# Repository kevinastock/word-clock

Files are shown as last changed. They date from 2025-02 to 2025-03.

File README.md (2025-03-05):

# Word Clock

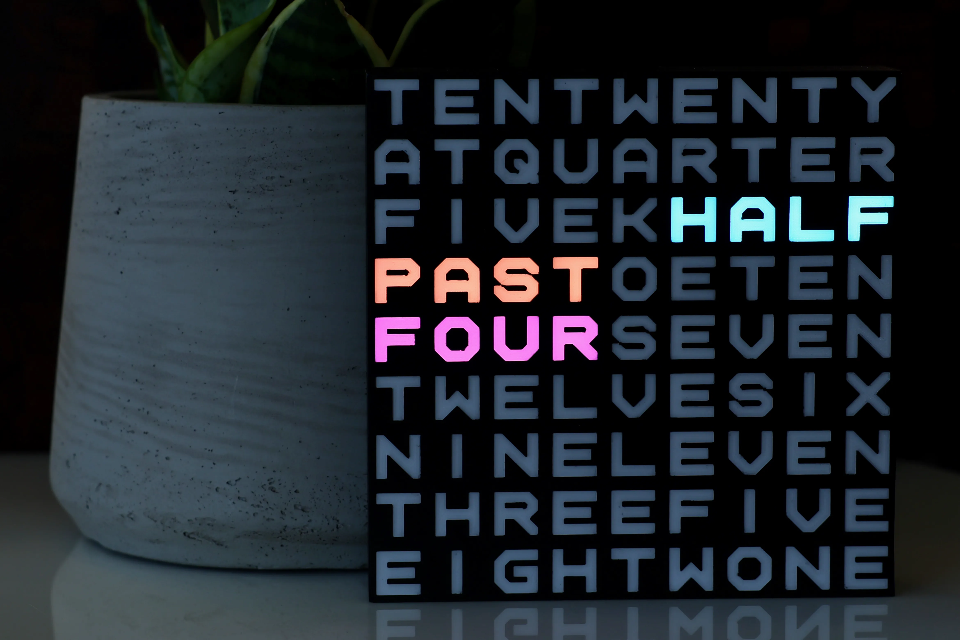
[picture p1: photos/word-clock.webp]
the clock


This project is a 3D-printed, word clock that displays the time using a 9×9 letter grid. 
The entire front enclosure was designed as a single piece that works as the display, LED adapter, light baffle, and diffuser. 
A TinyPICO microcontroller drives a matrix of APA102C LEDs and sets the time via NTP and [WorldTimeAPI](http://worldtimeapi.org).
Configuration is handled via an onboard accelerometer to adjust brightness, manually shift time zone, or reset WiFi credentials.
The backplate is secured with M2 heat-set inserts and hex socket screws, provides cable strain relief, and mounts for the electronics.

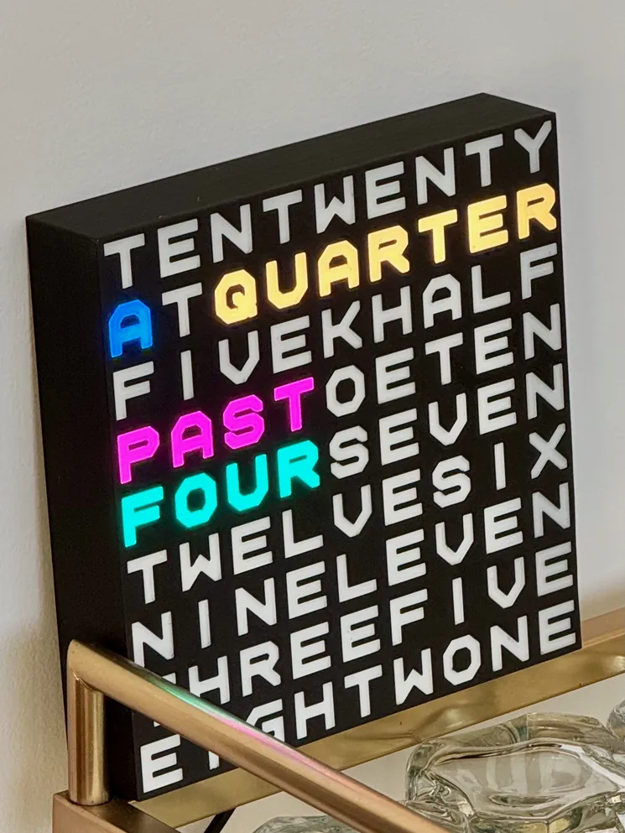
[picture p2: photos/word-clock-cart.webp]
the clock


## Bill of Materials

### Electronics
- **Microcontroller**: [TinyPICO](https://www.tinypico.com/)
- **Accelerometer**: [Adafruit LIS3DH](https://www.adafruit.com/product/2809)
- **Level Shifter**: [74AHCT125](https://www.adafruit.com/product/1787)
- **LEDs**: 16x16 APA102C LED matrix on a flexible pcb.
- **Protoboard**: [Amazon Link](https://www.amazon.com/gp/product/B071R3BFNL)
- **Wires / Connectors**: Assorted jumpers or soldered connections. Wago connectors were used in early prototypes but are optional.

### Mechanical
- **3D-Printed Front Enclosure**: Generated by `.scad` files in this repository and then exported to STL.
- **3D-Printed Backplate**: Also generated by `.scad` files, with holes sized for M2 heat-set inserts.
- **Heat Set Inserts**: [M2x8x2.5 Brass Knurled Inserts](https://www.amazon.com/Hilitchi-Knurled-Threaded-Function-Projects/dp/B07VFZWWXY)
- **Screws**: [M2x8 Hex Socket Head Screws](https://www.amazon.com/DYWISHKEY-Pieces-Socket-Screws-Wrench/dp/B07W5J19Y5)

### Tools & Supplies
- 3D Printer (capable of two-color printing or manual filament swaps). I used a Ultimaker UM3.
- Krylon Matte Finish (1311) or similar clear matte spray for surface finishing
- Soldering iron, solder, and basic electronics tools
- Heat gun or soldering iron for heat-set inserts

## 3D Printing

1. **Generate SCAD Files**: `python3 clock.py` will produce OpenSCAD files for both the front and backplate.
2. **Export to STL**:  Open each .scad file in OpenSCAD and render/export to .stl.
3. **Slicing**: The print uses three colors. If using a dual-extruder printer, insert a pause command in your slicer after the first few layers to swap from clear to white manually.
  If using a printer that can print three colors at once, the python code can be modified to produce three separate color pieces for the front.
4. **Post-Processing**: After printing, apply a coat of Krylon Matte Finish (1311) to the clock face. This helps diffuse light more evenly and improves the overall look.

## Firmware & Code

This project was built and uploaded using the Arduino IDE. Make sure you have the necessary ESP32 board definitions installed.

### Board Manager

You'll need to install `esp32` version `2.0.17`. The `3.x` versions will not work with this code.

### Required Libraries

| Library | Version | 
| --- | --- |
| Adafruit BusIO | 1.16.1 |
| Adafruit LIS3DH | 1.3.0 |
| Adafruit Unified Sensor | 1.1.14 |
| ArduinoJson | 7.0.4 |
| AsyncTCP (by dvarrel) | 1.1.4 |
| ESPAsyncTCP (by dvarrel) | 1.2.4 |
| ESPAsyncWebServer | 3.1.0 |
| FastLED | 3.7.8 |
| TinyPICO Helper Library | 1.5.0 |

## Electronics & Wiring

I don't have a real guide to wiring, here's a photo of one of the clocks internals:

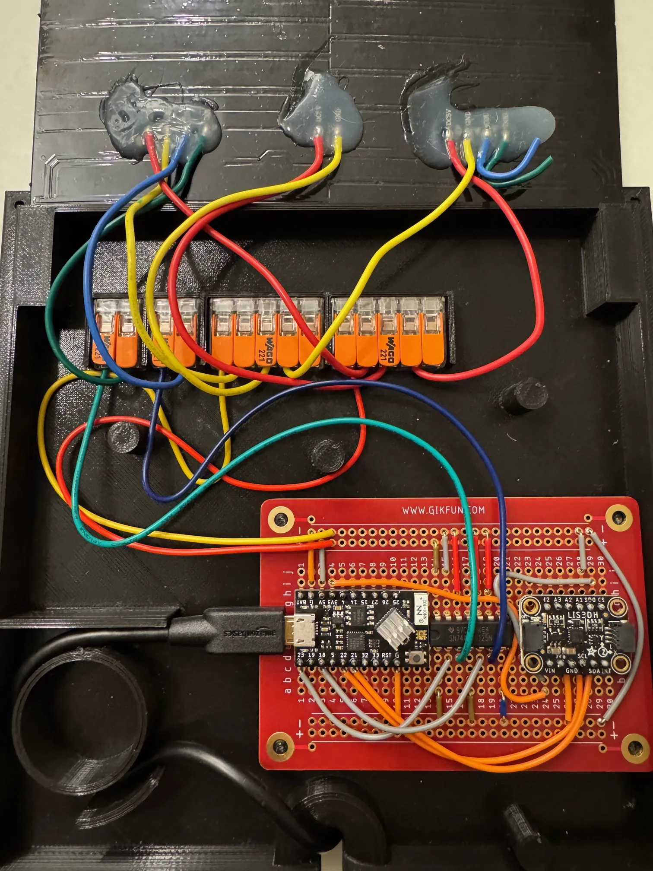
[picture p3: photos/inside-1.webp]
wiring

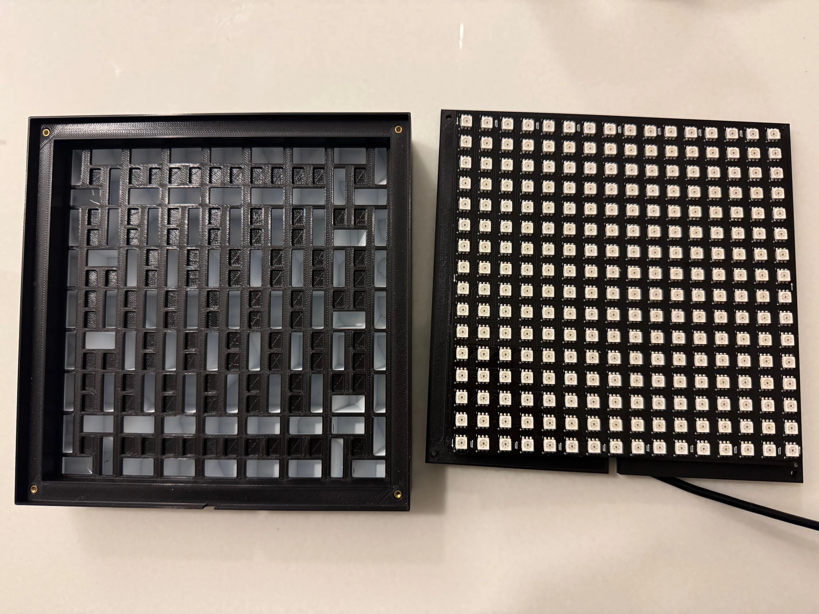
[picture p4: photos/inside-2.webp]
assembly


## License & Acknowledgments

Except as noted here, this project is released under the AGPL-3.0 license.

**Exceptions**:
 - Name Smile Font [Copyright © by Chequered Ink](https://chequered.ink) [FontSpace](https://www.fontspace.com/name-smile-font-f30803)
 - The forked code from [ESPConnect](https://github.com/ayushsharma82/ESPConnect) is under its GPL license.
 - The forked code from [NTPClient](https://github.com/arduino-libraries/NTPClient) is under its MIT license

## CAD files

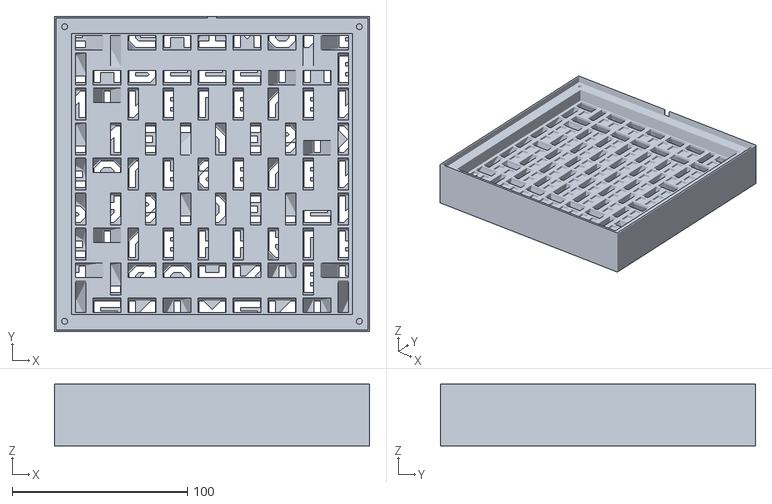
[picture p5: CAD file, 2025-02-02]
generated/clock-black.stl
180.0 x 180.0 x 35.3

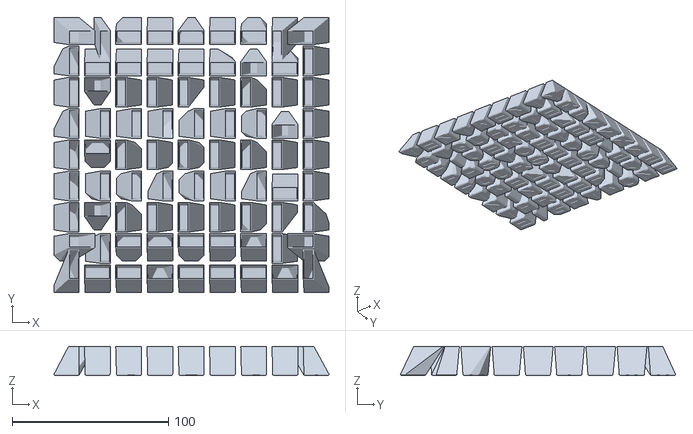
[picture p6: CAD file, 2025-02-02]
generated/clock-white.stl
176.0 x 176.0 x 18.7

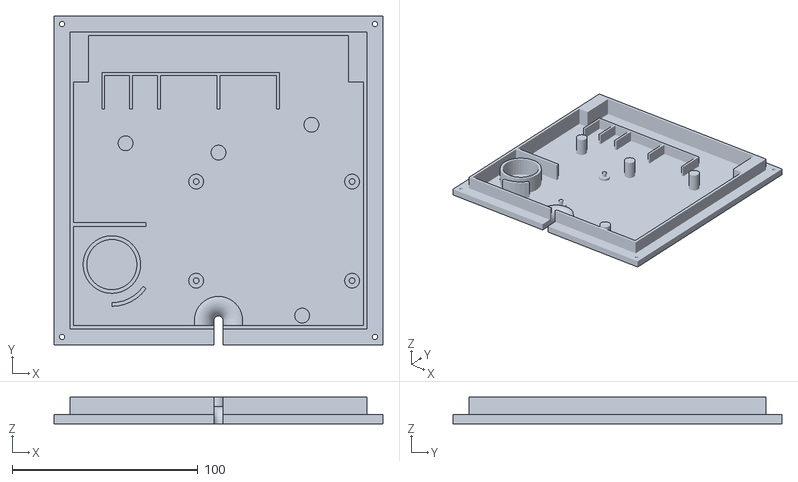
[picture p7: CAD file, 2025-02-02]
generated/clock-back.stl
177.0 x 177.0 x 14.5

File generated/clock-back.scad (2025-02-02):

module m5() {
    cube([177, 177, 5], center=false);
}

module m4() {
    translate([1.5, 1.5, 0])
        m5();
}

module m7() {
    cube([159.75, 159.75, 14.5], center=false);
}

module m6() {
    translate([10.125, 10.125, 0])
        m7();
}

module m3() {
    union() {
        m4();
        m6();
    }
}

module m10() {
    cylinder(h=1000000, d=2.85, center=false, $fn=20);
}

module m11() {
    cylinder(h=2, d=4.5, center=false, $fn=20);
}

module m9() {
    union() {
        m10();
        m11();
    }
}

module m8() {
    translate([5.832738110421965, 5.832738110421965, 0])
        m9();
}

module m14() {
    cylinder(h=1000000, d=2.85, center=false, $fn=20);
}

module m15() {
    cylinder(h=2, d=4.5, center=false, $fn=20);
}

module m13() {
    union() {
        m14();
        m15();
    }
}

module m12() {
    translate([5.832738110421965, 174.16726188957804, 0])
        m13();
}

module m18() {
    cylinder(h=1000000, d=2.85, center=false, $fn=20);
}

module m19() {
    cylinder(h=2, d=4.5, center=false, $fn=20);
}

module m17() {
    union() {
        m18();
        m19();
    }
}

module m16() {
    translate([174.16726188957804, 5.832738110421965, 0])
        m17();
}

module m22() {
    cylinder(h=1000000, d=2.85, center=false, $fn=20);
}

module m23() {
    cylinder(h=2, d=4.5, center=false, $fn=20);
}

module m21() {
    union() {
        m22();
        m23();
    }
}

module m20() {
    translate([174.16726188957804, 174.16726188957804, 0])
        m21();
}

module m25() {
    cube([155.75, 155.75, 1000000], center=false);
}

module m24() {
    translate([12.125, 12.125, 1.5])
        m25();
}

module m27() {
    cube([5, 29.25, 1000000], center=true);
}

module m26() {
    translate([90.0, 0, 0])
        m27();
}

module m29() {
    cylinder(h=1000000, d=5, center=true, $fn=40);
}

module m28() {
    translate([90.0, 14.625, 0])
        m29();
}

module m2() {
    difference() {
        m3();
        m8();
        m12();
        m16();
        m20();
        m24();
        m26();
        m28();
    }
}

module m33() {
    cylinder(h=3.5, d=8, center=true, $fn=40);
}

module m32() {
    translate([0, 0, 1.75])
        m33();
}

module m35() {
    cylinder(h=6.5, d=3.1, center=true, $fn=40);
}

module m34() {
    translate([0, 0, 3.25])
        m35();
}

module m31() {
    union() {
        m32();
        m34();
    }
}

module m30() {
    translate([161.875, 36.125, 0])
        m31();
}

module m39() {
    cylinder(h=3.5, d=8, center=true, $fn=40);
}

module m38() {
    translate([0, 0, 1.75])
        m39();
}

module m41() {
    cylinder(h=6.5, d=3.1, center=true, $fn=40);
}

module m40() {
    translate([0, 0, 3.25])
        m41();
}

module m37() {
    union() {
        m38();
        m40();
    }
}

module m36() {
    translate([77.975, 36.125, 0])
        m37();
}

module m45() {
    cylinder(h=3.5, d=8, center=true, $fn=40);
}

module m44() {
    translate([0, 0, 1.75])
        m45();
}

module m47() {
    cylinder(h=6.5, d=3.1, center=true, $fn=40);
}

module m46() {
    translate([0, 0, 3.25])
        m47();
}

module m43() {
    union() {
        m44();
        m46();
    }
}

module m42() {
    translate([161.875, 89.425, 0])
        m43();
}

module m51() {
    cylinder(h=3.5, d=8, center=true, $fn=40);
}

module m50() {
    translate([0, 0, 1.75])
        m51();
}

module m53() {
    cylinder(h=6.5, d=3.1, center=true, $fn=40);
}

module m52() {
    translate([0, 0, 3.25])
        m53();
}

module m49() {
    union() {
        m50();
        m52();
    }
}

module m48() {
    translate([77.975, 89.425, 0])
        m49();
}

module m55() {
    cylinder(h=14.5, d=8, center=false, $fn=40);
}

module m54() {
    translate([140, 120, 0])
        m55();
}

module m57() {
    cylinder(h=14.5, d=8, center=false, $fn=40);
}

module m56() {
    translate([40, 110, 0])
        m57();
}

module m59() {
    cylinder(h=14.5, d=8, center=false, $fn=40);
}

module m58() {
    translate([90.0, 105, 0])
        m59();
}

module m61() {
    cylinder(h=14.5, d=8, center=false, $fn=40);
}

module m60() {
    translate([135.0, 17.325, 0])
        m61();
}

module m63() {
    cube([8.0001, 25.0001, 14.5], center=false);
}

module m62() {
    translate([12.125, 142.875, 0])
        m63();
}

module m65() {
    cube([8.0001, 25.0001, 14.5], center=false);
}

module m64() {
    translate([159.875, 142.875, 0])
        m65();
}

module m67() {
    cube([38.849999999999994, 2, 14.5], center=false);
}

module m66() {
    translate([12.125, 65.275, 0])
        m67();
}

module m70() {
    cylinder(h=14.5, d=31, center=false, $fn=40);
}

module m71() {
    cylinder(h=1000000, d=27, center=false, $fn=40);
}

module m69() {
    difference() {
        m70();
        m71();
    }
}

module m68() {
    translate([32.625, 44.775, 0])
        m69();
}

module m74() {
    cylinder(h=14.5, d=45, center=false, $fn=40);
}

module m75() {
    cylinder(h=1000000, d=41, center=false, $fn=40);
}

module m77() {
    cube([1000000, 1000000, 1000000], center=true);
}

module m76() {
    translate([-500000.0, 0, 0])
        m77();
}

module m80() {
    cube([1000000, 1000000, 1000000], center=true);
}

module m79() {
    translate([0, 500000.0, 0])
        m80();
}

module m78() {
    rotate([0, 0, -35])
        m79();
}

module m73() {
    difference() {
        m74();
        m75();
        m76();
        m78();
    }
}

module m72() {
    translate([32.625, 44.775, 0])
        m73();
}

module m83() {
    cube([95.5, 19.5, 9.5], center=false);
}

module m85() {
    cube([13.5, 18, 1000000], center=false);
}

module m84() {
    translate([1.5, 0, 0])
        m85();
}

module m87() {
    cube([13.5, 18, 1000000], center=false);
}

module m86() {
    translate([16.5, 0, 0])
        m87();
}

module m89() {
    cube([30.5, 18, 1000000], center=false);
}

module m88() {
    translate([31.5, 0, 0])
        m89();
}

module m91() {
    cube([30.5, 18, 1000000], center=false);
}

module m90() {
    translate([63.5, 0, 0])
        m91();
}

module m82() {
    difference() {
        m83();
        m84();
        m86();
        m88();
        m90();
    }
}

module m81() {
    translate([27.25, 128.5, 0])
        m82();
}

module m100() {
    circle(r=8, $fn=40);
}

module m99() {
    translate([10.5, 0, 0])
        m100();
}

module m98() {
    rotate_extrude(convexity=10, $fn=40)
        m99();
}

module m102() {
    cube([1000000, 1000000, 1000000], center=true);
}

module m101() {
    translate([0, 0, -500000.0])
        m102();
}

module m104() {
    cube([1000000, 1000000, 1000000], center=true);
}

module m103() {
    translate([0, -500000.0, 0])
        m104();
}

module m97() {
    difference() {
        m98();
        m101();
        m103();
    }
}

module m105() {
    cylinder(h=1000000, d=26, center=true, $fn=40);
}

module m96() {
    intersection() {
        m97();
        m105();
    }
}

module m95() {
    translate([0, 2.5, 0])
        m96();
}

module m108() {
    cylinder(h=2.5, center=false, r=8, $fn=40);
}

module m107() {
    rotate([-90, 0, 0])
        m108();
}

module m106() {
    translate([10.5, 0, 0])
        m107();
}

module m111() {
    cylinder(h=2.5, center=false, r=8, $fn=40);
}

module m110() {
    rotate([-90, 0, 0])
        m111();
}

module m109() {
    translate([-10.5, 0, 0])
        m110();
}

module m94() {
    union() {
        m95();
        m106();
        m109();
    }
}

module m113() {
    cube([1000000, 1000000, 1000000], center=true);
}

module m112() {
    translate([0, 0, -500000.0])
        m113();
}

module m115() {
    cube([1000000, 1000000, 1000000], center=true);
}

module m114() {
    translate([500013.0, 0, 0])
        m115();
}

module m117() {
    cube([1000000, 1000000, 1000000], center=true);
}

module m116() {
    translate([-500013.0, 0, 0])
        m117();
}

module m93() {
    difference() {
        m94();
        m112();
        m114();
        m116();
    }
}

module m92() {
    translate([90.0, 12.125, 1.4999])
        m93();
}

module m1() {
    union() {
        m2();
        m30();
        m36();
        m42();
        m48();
        m54();
        m56();
        m58();
        m60();
        m62();
        m64();
        m66();
        m68();
        m72();
        m81();
        m92();
    }
}

module m121() {
    cylinder(h=500000.0, d=5, center=true, $fn=40);
}

module m120() {
    rotate([-45, 0, 0])
        m121();
}

module m123() {
    cube(1000000, center=true);
}

module m122() {
    translate([0, 0, -500001.0])
        m123();
}

module m125() {
    cube(1000000, center=true);
}

module m124() {
    translate([0, 0, 500012.5])
        m125();
}

module m119() {
    difference() {
        m120();
        m122();
        m124();
    }
}

module m118() {
    translate([16.125, 147.875, 0])
        m119();
}

module m129() {
    cylinder(h=500000.0, d=5, center=true, $fn=40);
}

module m128() {
    rotate([-45, 0, 0])
        m129();
}
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

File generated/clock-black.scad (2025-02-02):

use <Name Smile.otf>
module m1() {
    cube([180, 180, 35.260000000000005], center=false);
}

module m3() {
    cube([5.8, 8.2, 1.84], center=false);
}

module m2() {
    translate([12.1, 10.9, 18.66])
        m3();
}

module m5() {
    cube([5.8, 8.2, 1.84], center=false);
}

module m4() {
    translate([22.1, 10.9, 18.66])
        m5();
}

module m7() {
    cube([5.8, 8.2, 1.84], center=false);
}

module m6() {
    translate([32.1, 10.9, 18.66])
        m7();
}

module m9() {
    cube([5.8, 8.2, 1.84], center=false);
}

module m8() {
    translate([42.1, 10.9, 18.66])
        m9();
}

module m11() {
    cube([5.8, 8.2, 1.84], center=false);
}

module m10() {
    translate([52.1, 10.9, 18.66])
        m11();
}

module m13() {
    cube([5.8, 8.2, 1.84], center=false);
}

module m12() {
    translate([62.1, 10.9, 18.66])
        m13();
}

module m15() {
    cube([5.8, 8.2, 1.84], center=false);
}

module m14() {
    translate([72.1, 10.9, 18.66])
        m15();
}

module m17() {
    cube([5.8, 8.2, 1.84], center=false);
}

module m16() {
    translate([82.1, 10.9, 18.66])
        m17();
}

module m19() {
    cube([5.8, 8.2, 1.84], center=false);
}

module m18() {
    translate([92.1, 10.9, 18.66])
        m19();
}

module m21() {
    cube([5.8, 8.2, 1.84], center=false);
}

module m20() {
    translate([102.1, 10.9, 18.66])
        m21();
}

module m23() {
    cube([5.8, 8.2, 1.84], center=false);
}

module m22() {
    translate([112.1, 10.9, 18.66])
        m23();
}

module m25() {
    cube([5.8, 8.2, 1.84], center=false);
}

module m24() {
    translate([122.1, 10.9, 18.66])
        m25();
}

module m27() {
    cube([5.8, 8.2, 1.84], center=false);
}

module m26() {
    translate([132.1, 10.9, 18.66])
        m27();
}

module m29() {
    cube([5.8, 8.2, 1.84], center=false);
}

module m28() {
    translate([142.1, 10.9, 18.66])
        m29();
}

module m31() {
    cube([5.8, 8.2, 1.84], center=false);
}

module m30() {
    translate([152.1, 10.9, 18.66])
        m31();
}

module m33() {
    cube([5.8, 8.2, 1.84], center=false);
}

module m32() {
    translate([162.1, 10.9, 18.66])
        m33();
}

module m35() {
    cube([5.8, 8.2, 1.84], center=false);
}

module m34() {
    translate([12.1, 20.9, 18.66])
        m35();
}

module m37() {
    cube([5.8, 8.2, 1.84], center=false);
}

module m36() {
    translate([22.1, 20.9, 18.66])
        m37();
}

module m39() {
    cube([5.8, 8.2, 1.84], center=false);
}

module m38() {
    translate([32.1, 20.9, 18.66])
        m39();
}

module m41() {
    cube([5.8, 8.2, 1.84], center=false);
}

module m40() {
    translate([42.1, 20.9, 18.66])
        m41();
}

module m43() {
    cube([5.8, 8.2, 1.84], center=false);
}

module m42() {
    translate([52.1, 20.9, 18.66])
        m43();
}

module m45() {
    cube([5.8, 8.2, 1.84], center=false);
}

module m44() {
    translate([62.1, 20.9, 18.66])
        m45();
}

module m47() {
    cube([5.8, 8.2, 1.84], center=false);
}

module m46() {
    translate([72.1, 20.9, 18.66])
        m47();
}

module m49() {
    cube([5.8, 8.2, 1.84], center=false);
}

module m48() {
    translate([82.1, 20.9, 18.66])
        m49();
}

module m51() {
    cube([5.8, 8.2, 1.84], center=false);
}

module m50() {
    translate([92.1, 20.9, 18.66])
        m51();
}

module m53() {
    cube([5.8, 8.2, 1.84], center=false);
}

module m52() {
    translate([102.1, 20.9, 18.66])
        m53();
}

module m55() {
    cube([5.8, 8.2, 1.84], center=false);
}

module m54() {
    translate([112.1, 20.9, 18.66])
        m55();
}

module m57() {
    cube([5.8, 8.2, 1.84], center=false);
}

module m56() {
    translate([122.1, 20.9, 18.66])
        m57();
}

module m59() {
    cube([5.8, 8.2, 1.84], center=false);
}

module m58() {
    translate([132.1, 20.9, 18.66])
        m59();
}

module m61() {
    cube([5.8, 8.2, 1.84], center=false);
}

module m60() {
    translate([142.1, 20.9, 18.66])
        m61();
}

module m63() {
    cube([5.8, 8.2, 1.84], center=false);
}

module m62() {
    translate([152.1, 20.9, 18.66])
        m63();
}

module m65() {
    cube([5.8, 8.2, 1.84], center=false);
}

module m64() {
    translate([162.1, 20.9, 18.66])
        m65();
}

module m67() {
    cube([5.8, 8.2, 1.84], center=false);
}

module m66() {
    translate([12.1, 30.9, 18.66])
        m67();
}

module m69() {
    cube([5.8, 8.2, 1.84], center=false);
}

module m68() {
    translate([22.1, 30.9, 18.66])
        m69();
}

module m71() {
    cube([5.8, 8.2, 1.84], center=false);
}

module m70() {
    translate([32.1, 30.9, 18.66])
        m71();
}

module m73() {
    cube([5.8, 8.2, 1.84], center=false);
}

module m72() {
    translate([42.1, 30.9, 18.66])
        m73();
}

module m75() {
    cube([5.8, 8.2, 1.84], center=false);
}

module m74() {
    translate([52.1, 30.9, 18.66])
        m75();
}

module m77() {
    cube([5.8, 8.2, 1.84], center=false);
}

module m76() {
    translate([62.1, 30.9, 18.66])
        m77();
}

module m79() {
    cube([5.8, 8.2, 1.84], center=false);
}

module m78() {
    translate([72.1, 30.9, 18.66])
        m79();
}

module m81() {
    cube([5.8, 8.2, 1.84], center=false);
}

module m80() {
    translate([82.1, 30.9, 18.66])
        m81();
}

module m83() {
    cube([5.8, 8.2, 1.84], center=false);
}

module m82() {
    translate([92.1, 30.9, 18.66])
        m83();
}

module m85() {
    cube([5.8, 8.2, 1.84], center=false);
}

module m84() {
    translate([102.1, 30.9, 18.66])
        m85();
}

module m87() {
    cube([5.8, 8.2, 1.84], center=false);
}

module m86() {
    translate([112.1, 30.9, 18.66])
        m87();
}

module m89() {
    cube([5.8, 8.2, 1.84], center=false);
}

module m88() {
    translate([122.1, 30.9, 18.66])
        m89();
}

module m91() {
    cube([5.8, 8.2, 1.84], center=false);
}

module m90() {
    translate([132.1, 30.9, 18.66])
        m91();
}

module m93() {
    cube([5.8, 8.2, 1.84], center=false);
}

module m92() {
    translate([142.1, 30.9, 18.66])
        m93();
}

module m95() {
    cube([5.8, 8.2, 1.84], center=false);
}

module m94() {
    translate([152.1, 30.9, 18.66])
        m95();
}

module m97() {
    cube([5.8, 8.2, 1.84], center=false);
}

module m96() {
    translate([162.1, 30.9, 18.66])
        m97();
}

module m99() {
    cube([5.8, 8.2, 1.84], center=false);
}

module m98() {
    translate([12.1, 40.9, 18.66])
        m99();
}

module m101() {
    cube([5.8, 8.2, 1.84], center=false);
}

module m100() {
    translate([22.1, 40.9, 18.66])
        m101();
}

module m103() {
    cube([5.8, 8.2, 1.84], center=false);
}

module m102() {
    translate([32.1, 40.9, 18.66])
        m103();
}

module m105() {
    cube([5.8, 8.2, 1.84], center=false);
}

module m104() {
    translate([42.1, 40.9, 18.66])
        m105();
}

module m107() {
    cube([5.8, 8.2, 1.84], center=false);
}

module m106() {
    translate([52.1, 40.9, 18.66])
        m107();
}

module m109() {
    cube([5.8, 8.2, 1.84], center=false);
}

module m108() {
    translate([62.1, 40.9, 18.66])
        m109();
}

module m111() {
    cube([5.8, 8.2, 1.84], center=false);
}

module m110() {
    translate([72.1, 40.9, 18.66])
        m111();
}

module m113() {
    cube([5.8, 8.2, 1.84], center=false);
}

module m112() {
    translate([82.1, 40.9, 18.66])
        m113();
}

module m115() {
    cube([5.8, 8.2, 1.84], center=false);
}

module m114() {
    translate([92.1, 40.9, 18.66])
        m115();
}

module m117() {
    cube([5.8, 8.2, 1.84], center=false);
}

module m116() {
    translate([102.1, 40.9, 18.66])
        m117();
}

module m119() {
    cube([5.8, 8.2, 1.84], center=false);
}

module m118() {
    translate([112.1, 40.9, 18.66])
        m119();
}

module m121() {
    cube([5.8, 8.2, 1.84], center=false);
}

module m120() {
    translate([122.1, 40.9, 18.66])
        m121();
}

module m123() {
    cube([5.8, 8.2, 1.84], center=false);
}

module m122() {
    translate([132.1, 40.9, 18.66])
        m123();
}

module m125() {
    cube([5.8, 8.2, 1.84], center=false);
}

module m124() {
    translate([142.1, 40.9, 18.66])
        m125();
}

module m127() {
    cube([5.8, 8.2, 1.84], center=false);
}

module m126() {
    translate([152.1, 40.9, 18.66])
        m127();
}

module m129() {
    cube([5.8, 8.2, 1.84], center=false);
}

module m128() {
    translate([162.1, 40.9, 18.66])
        m129();
}

module m131() {
    cube([5.8, 8.2, 1.84], center=false);
}

module m130() {
    translate([12.1, 50.9, 18.66])
        m131();
}

module m133() {
    cube([5.8, 8.2, 1.84], center=false);
}

module m132() {
    translate([22.1, 50.9, 18.66])
        m133();
}

module m135() {
    cube([5.8, 8.2, 1.84], center=false);
}

module m134() {
    translate([32.1, 50.9, 18.66])
        m135();
}

module m137() {
    cube([5.8, 8.2, 1.84], center=false);
}

module m136() {
    translate([42.1, 50.9, 18.66])
        m137();
}

module m139() {
    cube([5.8, 8.2, 1.84], center=false);
}
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

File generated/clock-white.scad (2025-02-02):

use <Name Smile.otf>
module m10() {
    text("T", font="Name Smile", halign="center", valign="center", size=14.0);
}

module m9() {
    rotate([180, 0, 0])
        m10();
}

module m8() {
    translate([10.0, 10.0, 0])
        m9();
}

module m7() {
    linear_extrude(height=0.0001, center=false)
        m8();
}

module m6() {
    translate([0, 0, 0.5])
        m7();
}

module m12() {
    cube([5.8, 18.2, 0.0001], center=false);
}

module m11() {
    translate([12.1, 10.9, 18.66])
        m12();
}

module m5() {
    union() {
        m6();
        m11();
    }
}

module m4() {
    hull() {
        m5();
    }
}

module m13() {
    cube(0.8, center=true);
}

module m3() {
    minkowski() {
        m4();
        m13();
    }
}

module m15() {
    cube([1000000, 1000000, 0.8], center=false);
}

module m14() {
    difference() {
        m4();
        m15();
    }
}

module m2() {
    difference() {
        m3();
        m14();
    }
}

module m17() {
    cube([1000000, 1000000, 18.16], center=false);
}

module m16() {
    translate([0, 0, 0.5])
        m17();
}

module m1() {
    intersection() {
        m2();
        m16();
    }
}

module m27() {
    text("E", font="Name Smile", halign="center", valign="center", size=14.0);
}

module m26() {
    rotate([180, 0, 0])
        m27();
}

module m25() {
    translate([30.0, 10.0, 0])
        m26();
}

module m24() {
    linear_extrude(height=0.0001, center=false)
        m25();
}

module m23() {
    translate([0, 0, 0.5])
        m24();
}

module m29() {
    cube([15.8, 8.2, 0.0001], center=false);
}

module m28() {
    translate([22.1, 10.9, 18.66])
        m29();
}

module m22() {
    union() {
        m23();
        m28();
    }
}

module m21() {
    hull() {
        m22();
    }
}

module m30() {
    cube(0.8, center=true);
}

module m20() {
    minkowski() {
        m21();
        m30();
    }
}

module m32() {
    cube([1000000, 1000000, 0.8], center=false);
}

module m31() {
    difference() {
        m21();
        m32();
    }
}

module m19() {
    difference() {
        m20();
        m31();
    }
}

module m34() {
    cube([1000000, 1000000, 18.16], center=false);
}

module m33() {
    translate([0, 0, 0.5])
        m34();
}

module m18() {
    intersection() {
        m19();
        m33();
    }
}

module m44() {
    text("N", font="Name Smile", halign="center", valign="center", size=14.0);
}

module m43() {
    rotate([180, 0, 0])
        m44();
}

module m42() {
    translate([50.0, 10.0, 0])
        m43();
}

module m41() {
    linear_extrude(height=0.0001, center=false)
        m42();
}

module m40() {
    translate([0, 0, 0.5])
        m41();
}

module m46() {
    cube([15.8, 8.2, 0.0001], center=false);
}

module m45() {
    translate([42.1, 10.9, 18.66])
        m46();
}

module m39() {
    union() {
        m40();
        m45();
    }
}

module m38() {
    hull() {
        m39();
    }
}

module m47() {
    cube(0.8, center=true);
}

module m37() {
    minkowski() {
        m38();
        m47();
    }
}

module m49() {
    cube([1000000, 1000000, 0.8], center=false);
}

module m48() {
    difference() {
        m38();
        m49();
    }
}

module m36() {
    difference() {
        m37();
        m48();
    }
}

module m51() {
    cube([1000000, 1000000, 18.16], center=false);
}

module m50() {
    translate([0, 0, 0.5])
        m51();
}

module m35() {
    intersection() {
        m36();
        m50();
    }
}

module m61() {
    text("T", font="Name Smile", halign="center", valign="center", size=14.0);
}

module m60() {
    rotate([180, 0, 0])
        m61();
}

module m59() {
    translate([70.0, 10.0, 0])
        m60();
}

module m58() {
    linear_extrude(height=0.0001, center=false)
        m59();
}

module m57() {
    translate([0, 0, 0.5])
        m58();
}

module m63() {
    cube([15.8, 8.2, 0.0001], center=false);
}

module m62() {
    translate([62.1, 10.9, 18.66])
        m63();
}

module m56() {
    union() {
        m57();
        m62();
    }
}

module m55() {
    hull() {
        m56();
    }
}

module m64() {
    cube(0.8, center=true);
}

module m54() {
    minkowski() {
        m55();
        m64();
    }
}

module m66() {
    cube([1000000, 1000000, 0.8], center=false);
}

module m65() {
    difference() {
        m55();
        m66();
    }
}

module m53() {
    difference() {
        m54();
        m65();
    }
}

module m68() {
    cube([1000000, 1000000, 18.16], center=false);
}

module m67() {
    translate([0, 0, 0.5])
        m68();
}

module m52() {
    intersection() {
        m53();
        m67();
    }
}

module m78() {
    text("W", font="Name Smile", halign="center", valign="center", size=14.0);
}

module m77() {
    rotate([180, 0, 0])
        m78();
}

module m76() {
    translate([90.0, 10.0, 0])
        m77();
}

module m75() {
    linear_extrude(height=0.0001, center=false)
        m76();
}

module m74() {
    translate([0, 0, 0.5])
        m75();
}

module m80() {
    cube([15.8, 8.2, 0.0001], center=false);
}

module m79() {
    translate([82.1, 10.9, 18.66])
        m80();
}

module m73() {
    union() {
        m74();
        m79();
    }
}

module m72() {
    hull() {
        m73();
    }
}

module m81() {
    cube(0.8, center=true);
}

module m71() {
    minkowski() {
        m72();
        m81();
    }
}

module m83() {
    cube([1000000, 1000000, 0.8], center=false);
}

module m82() {
    difference() {
        m72();
        m83();
    }
}

module m70() {
    difference() {
        m71();
        m82();
    }
}

module m85() {
    cube([1000000, 1000000, 18.16], center=false);
}

module m84() {
    translate([0, 0, 0.5])
        m85();
}

module m69() {
    intersection() {
        m70();
        m84();
    }
}

module m95() {
    text("E", font="Name Smile", halign="center", valign="center", size=14.0);
}

module m94() {
    rotate([180, 0, 0])
        m95();
}

module m93() {
    translate([110.0, 10.0, 0])
        m94();
}
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

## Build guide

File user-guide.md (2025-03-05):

# Word Clock User Guide

## Getting Started

### Placement

1. Placement Options:
	- On a Surface: Place the clock upright on any flat surface like a table or shelf.
	- Wall Mounting: Use the two holes on the back to hang the clock on nails in the wall.
2. Connect Power:
  - Plug the power cable into a USB power supply.

### Connecting to Wi-Fi

The clock needs a Wi-Fi connection to display the time.

1. Initial Setup:
  - When first powered on, the clock displays “WI FI” in red, indicating it needs Wi-Fi configuration.
2. Connect to the Clock’s Network:
  - On your smartphone or computer, go to Wi-Fi settings.
  - Connect to the network named “Wordclock”.
3. Enter Your Home Wi-Fi Details:
  - A setup page should appear automatically. If not, open a web browser, and you will be redirected.
  - Follow the on-screen instructions to enter your home Wi-Fi name and password.
4. Completion:
  - Once connected, the clock will display the time using words.

## Using Your Word Clock

### Adjusting Brightness

Lay the clock face up (lying on its back). After 5 seconds, the brightness resets to maximum. The clock will then dim slightly every few seconds. Stand the Clock Upright when the desired brightness is reached.

### Setting Off Hours (turn off the display at certain times)

1. Set off hours: Lay the clock face down, i.e., letters touching the table. Leave it face-down for the duration you want the display to be off daily. For example, turn it off between 10 pm and 6 am by laying it face down at 10 pm and moving it back upright at 6 am. Stand the clock upright when done.
2. Clear Off Hours: To remove off hours, lay the clock face down for between 5 seconds and 5 minutes and then stand it upright.

### Adjusting Time Zone

If the displayed time is incorrect due to time zone settings, adjust it as follows:

1. Decrease the time zone by one hour: Lay the Clock on its left side. Every 5 seconds, the time zone decreases by one hour. Stand the clock upright when the correct time is displayed.
2. Increase the time zone by One Hour: Lay the Clock on its right side. Every 5 seconds, the time zone increases by one hour. Stand the clock upright when the correct time is displayed.
3. Reset to automatic time zone: Lay the clock face up for over one minute. The clock will revert to automatic time zone detection.

Note: Manually setting the time zone disables automatic Daylight Saving Time adjustments.

### Resetting Wi-Fi Configuration

To reset the Wi-Fi configuration, turn the clock upside down. After 5 seconds, Wi-Fi settings will reset. The clock will display “WI FI” in red. Reconfigure Wi-Fi as per "Connecting to Wi-Fi".

## Troubleshooting

### Wi-Fi Issues

- “WI FI” displayed in red indicates that Wi-Fi is not configured. Follow the steps in "Connecting to Wi-Fi".
- “WI FI” in yellow indicates the clock is configured but cannot connect to your Wi-Fi network. Solutions:
	- Check your Wi-Fi password and network availability.
	- Reset Wi-Fi settings (see below).
- “WI FI” displayed in blue indicates the clock is connected to Wi-Fi but cannot access time services. Solutions:
  - Wait a bit while it retries.
	- Ensure your internet connection is active.
	- Try resetting Wi-Fi settings.

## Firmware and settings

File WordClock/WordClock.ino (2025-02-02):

/*
ESP32 word clock

https://api.ip2location.io/?format=json
http://worldtimeapi.org/api/ip

TODO:
- Confirm turning display off for some time works correctly.
- Just confirm everything. Write documentation and test all the features.

*/

#define DEBUG 0

#ifdef DEBUG
#define DPRINT(...)    Serial.print(__VA_ARGS__)
#define DPRINTLN(...)  Serial.println(__VA_ARGS__)
#else
#define DPRINT(...)     //blank line
#define DPRINTLN(...)   //blank line
#endif

#include <TinyPICO.h>
#define SPI_DATA 23
#define SPI_CLOCK 18

/* ESP32 Dependencies */
#include <ESPAsyncWebServer.h>
#include <esp_bt.h>
#include <HTTPClient.h>
#include <ArduinoJson.h>

#include <WiFiUdp.h>
#include "NTPClient.h"

#include "ESPConnect.h"
#include <FastLED.h>

#include <Wire.h>
#include <Adafruit_LIS3DH.h>
#include <Adafruit_Sensor.h>
#include "Preferences.h"

Adafruit_LIS3DH accel = Adafruit_LIS3DH();

#define NUM_LEDS (256)
CRGB leds[NUM_LEDS];

unsigned long buffered_minute = 60; // We don't need hours because this is just used to detect when to shift buffers
CHSV before[NUM_LEDS];
CHSV after[NUM_LEDS];
CHSV kevin[NUM_LEDS];

// The color to show the wifi message in.
CRGB wifi_color = CRGB::Green;

const uint8_t LETTER_LEDS[9][9][2] = {
    {{0,1}, {31,32}, {63,64}, {95,96}, {127,128}, {159,160}, {191,192}, {223,224}, {255,254}},
    {{2,29}, {33,34}, {61,66}, {93,98}, {125,130}, {157,162}, {189,194}, {222,221}, {226,253}},
    {{3,4}, {27,36}, {60,59}, {92,91}, {124,123}, {156,155}, {188,187}, {220,219}, {252,251}},
    {{5,6}, {37,38}, {69,70}, {101,102}, {133,134}, {165,166}, {197,198}, {218,229}, {250,249}},
    {{7,8}, {23,40}, {56,55}, {88,87}, {120,119}, {152,151}, {184,183}, {216,215}, {248,247}},
    {{9,10}, {41,42}, {73,74}, {105,106}, {137,138}, {169,170}, {201,202}, {214,233}, {246,245}},
    {{11,12}, {19,44}, {52,51}, {84,83}, {116,115}, {148,147}, {180,179}, {212,211}, {244,243}},
    {{13,14}, {18,45}, {50,77}, {82,109}, {114,141}, {146,173}, {178,205}, {210,237}, {242,241}},
    {{15,16}, {46,47}, {48,79}, {80,111}, {112,143}, {144,175}, {176,207}, {209,208}, {239,240}}
};

WiFiUDP ntpUDP;
NTPClient timeClient(ntpUDP, -4 * 3600);

AsyncWebServer server(80);
JsonDocument doc;
TinyPICO tp = TinyPICO();

bool timeLoaded = false;

int button = -1;
unsigned long button_since = 0;
unsigned long button_start = 0;
bool button_once = true;

#define MILLIS_PER_CYCLE (1000L*60*60*12)
#define MILLIS_PER_HOUR (1000L*60*60)
#define MILLIS_PER_MINUTE (1000L*60)
#define MILLIS_PER_SECOND (1000)
#define FIVE_MIN (60*5)
#define FIVE_MIN_MILLIS (1000*60*5)

#define FADE_MILLIS (3000L)
#define FADE_START (FIVE_MIN_MILLIS/2 - FADE_MILLIS/2)
#define FADE_END (FIVE_MIN_MILLIS/2 + FADE_MILLIS/2)

#define NO_WIFI (1)
#define NO_API (2)
#define SUCCESS (3)

#define ROTATE_LEFT (0)
#define ROTATE_RIGHT (1)
#define FACE_UP (4)
#define FACE_DOWN (5)
#define UPSIDE_DOWN (3)
#define NORMAL_POSITION (2)

#define UNSET_MANUAL_TZ_OFFSET (-1)

// PERSISTED VALUES
uint8_t led_value;
uint8_t _stored_led_value;

long manual_tz_offset;
long _stored_manual_tz_offset;

uint32_t display_off_start;
uint32_t _stored_display_off_start;

uint32_t display_off_end;
uint32_t _stored_display_off_end;

void read_stored_values() {
  Preferences preferences;
  preferences.begin("clock", false);

  DPRINTLN("Loading stored values:");

  led_value = _stored_led_value = preferences.getUChar("lv", 255);
  manual_tz_offset = _stored_manual_tz_offset = preferences.getLong("mt", UNSET_MANUAL_TZ_OFFSET);
  display_off_start = _stored_display_off_start = preferences.getUInt("ds", 1000000);
  display_off_end = _stored_display_off_end = preferences.getUInt("de", 1000000);

  DPRINT("LED: ");
  DPRINTLN(led_value);

  DPRINT("TZ: ");
  DPRINTLN(manual_tz_offset);

  DPRINT("Off Start: ");
  DPRINTLN(display_off_start);

  DPRINT("Off End: ");
  DPRINTLN(display_off_end);

  preferences.end();
}

void write_stored_values() {
  if (led_value != _stored_led_value 
      || manual_tz_offset != _stored_manual_tz_offset 
      || display_off_start != _stored_display_off_start
      || display_off_end != _stored_display_off_end) {

    DPRINT("LED: ");
    DPRINT(_stored_led_value);
    DPRINT(" -> ");
    DPRINTLN(led_value);

    DPRINT("TZ: ");
    DPRINT(_stored_manual_tz_offset);
    DPRINT(" -> ");
    DPRINTLN(manual_tz_offset);

    DPRINT("Off Start: ");
    DPRINT(_stored_display_off_start);
    DPRINT(" -> ");
    DPRINTLN(display_off_start);

    DPRINT("Off End: ");
    DPRINT(_stored_display_off_end);
    DPRINT(" -> ");
    DPRINTLN(display_off_end);

    Preferences preferences;
    preferences.begin("clock", false);
    preferences.putUChar("lv", led_value);
    preferences.putLong("mt", manual_tz_offset);
    preferences.putUInt("ds", display_off_start);
    preferences.putUInt("de", display_off_end);
    preferences.end();

    _stored_led_value = led_value;
    _stored_manual_tz_offset = manual_tz_offset;
    _stored_display_off_start = display_off_start;
    _stored_display_off_end = display_off_end;
  } else {
    DPRINTLN("No writes to preferences needed");
  }
}


int fetch_timezone(String url, String key) {
  HTTPClient http;
  http.begin(url);
  int httpCode = http.GET();
  int newOffset = -1; // Sentinel value; offset must be a multiple of 60 to be real.

  if (httpCode == 200) {
    DeserializationError error = deserializeJson(doc, http.getStream());
    if (error) {
      DPRINTLN("Failed to parse json from " + url);
    } else {
      const char* datetime = doc[key]; // "-05:00"
      if (datetime != NULL) {
        int h, m;
        int filled = sscanf(datetime, "%d:%d", &h, &m);
        if (filled != 2) {
          DPRINT("Could not parse offset from worldtimeapi: ");
          DPRINTLN(filled);
        } else {
          newOffset = h*3600 + m*60;
        }
      } else {
        DPRINTLN("Key not found in doc.");
      }
    }
  } else {
    DPRINTLN("Failed to connect to " + url);
  }
  http.end();

  return newOffset;
}

void set_time_zone() {
  // - if manual is set, we just use it (easy)
  // - if auto, and we're in startup: just leave it alone, will default to gmt
  // - if auto, and this is a regular update, we don't care this failed once. (easy)

  if (manual_tz_offset != UNSET_MANUAL_TZ_OFFSET) {
    // If a manual tz offset was specified, we use that one.
    DPRINTLN("Timezone was manually set");
    timeClient.setTimeOffset(manual_tz_offset);
    return;
  }

  DPRINTLN("Fetching from worldtimeapi");
  int newOffset = fetch_timezone("http://worldtimeapi.org/api/ip", "utc_offset");

  /*
  // Ugh, this doesn't do DST.
  if (newOffset == -1) {
    DPRINTLN("Fetching from ip2location");
    newOffset = fetch_timezone("https://api.ip2location.io", "time_zone");
  }
  */

  if (newOffset == -1) {
    DPRINTLN("ERROR: Could not set time zone from any sources");
  } else if (newOffset != timeClient.getTimeOffset()) {
    DPRINT("Setting timezone: ");
    DPRINTLN(newOffset);
    timeClient.setTimeOffset(newOffset);
  }
}

int get_time() {
  // Let's get this over with fast.
  setCpuFrequencyMhz(240);

  int ret = NO_WIFI;
  DPRINTLN("Getting the time");
  
  ESPConnect.connect();

  if (ESPConnect.isConnected()) {
    DPRINTLN("Connected to WiFi");
    DPRINTLN("IPAddress: "+WiFi.localIP().toString());

    // Gross, but sometimes the network doesn't work right away after connection.
    delay(2000);

    ret = NO_API;
    timeClient.begin();
    
    set_time_zone();

    if (!timeClient.forceUpdate()) {
      DPRINTLN("NTP isn't working?!");
    } else {
      DPRINT("Got time & timezone: ");
      DPRINTLN(timeClient.getFormattedTime());
      ret = SUCCESS;
    }

    // disconnect the wifi
    WiFi.disconnect(true, true);
    WiFi.mode(WIFI_OFF);
    DPRINTLN("Disconnected from WiFi");
  } else {
    DPRINTLN("Failed to connect to WiFi");
  }

  // And let's not melt the cpu.
  setCpuFrequencyMhz(80);
  return ret;
}

#ifdef DEBUG
int last_on = 0;
#endif

void show_leds() {
#ifdef DEBUG
  int on = 0;
  for (int i = 0; i < NUM_LEDS; i++) {
    if (leds[i].r > 0 || leds[i].g > 0 || leds[i].b > 0) {
      on++;
    }
  }

  if (on != last_on) {
    DPRINT("Total leds on = ");
    DPRINTLN(on);
    last_on = on;
  }

  // This check is a bit goofy, but I don't want to explode more boards. Check that we never need a bigger value?
  // HALF PAST ELEVEN -> TWENTY FIVE TO TWELVE is the biggest I think?
  if (on < 70) {
    FastLED.show();
  } else {
    DPRINTLN("Oh no! We tried to draw too many leds at once!");
  }
#else
  FastLED.show();
#endif
}

void draw_buffer(CHSV* a) {
  for (int i = 0; i < NUM_LEDS; i++) {
    leds[i] = CHSV(a[i].h, a[i].s, a[i].v > 0 ? led_value : 0);
  }
  show_leds();
}

void draw_buffers(CHSV* a, CHSV* b, float x) {
  for (int i = 0; i < NUM_LEDS; i++) {
    uint8_t h, s, v;
    if (a[i].v == 0 && b[i].v == 0) {
      h = a[i].h;
      s = a[i].s;
      v = 0;
    } else if (a[i].v == 0) {
      h = b[i].h;
      s = b[i].s;
      v = led_value*(x);
    } else if (b[i].v == 0) {
      h = a[i].h;
      s = a[i].s;
      v = led_value*(1.0-x);
    } else {
      uint8_t dh = b[i].h - a[i].h; // This should behave like fastled's shortest_hue
      if (dh < 128) {
        h = a[i].h + (uint8_t)(dh*x);
      } else {
        dh = -dh;
        h = a[i].h - (uint8_t)(dh*x);
      }
      //  h = a[i].h*(1.0-x) + b[i].h*x;
      s = a[i].s*(1.0-x) + b[i].s*x;
      v = (a[i].v > 0 ? led_value : 0)*(1.0-x) + (b[i].v > 0 ? led_value : 0)*x;
    }
    leds[i] = CHSV(h, s, v);
  }
  show_leds();
}

void draw_word(CHSV* dest, uint8_t row, uint8_t col, uint8_t len, CHSV color) {
  for (uint8_t i = 0; i < len; i++) {
    dest[LETTER_LEDS[row][col+i][0]] = color;
    dest[LETTER_LEDS[row][col+i][1]] = color;
  }
}

void draw_time(CHSV* dest, int hour, int minute) {
  for (int i = 0; i < NUM_LEDS; i++) {
    dest[i] = CHSV(0,0,0);
  }

  // TODO: Pick better random colors. i.e., never two which are too close to each other
  CHSV color0 = CHSV(esp_random() % 256, 255, 255);
  CHSV color1 = CHSV(esp_random() % 256, 255, 255);
  CHSV color2 = CHSV(esp_random() % 256, 255, 255);
  CHSV color3 = CHSV(esp_random() % 256, 255, 255);
  
  if (minute == 5 || minute == 55 || minute == 25 || minute == 35) {
    draw_word(dest,2,0,4,color1); // FIVE
  }

  if (minute == 10 || minute == 50) {
    draw_word(dest,0,0,3,color1); // TEN
  }

  if (minute == 15 || minute == 45) {
    draw_word(dest,1,0,1,color0); 
    draw_word(dest,1,2,7,color1); // A QUARTER
  }

  if (minute == 20 || minute == 40 || minute == 25 || minute == 35) {
    // this is color zero because we don't want it to be the same color as five, and it'll never be on at the same time as 'A'
    draw_word(dest,0,3,6,color0); // TWENTY
  }

  if (minute == 30) {
    draw_word(dest,2,5,4,color1); // HALF
  }

  if (minute > 0 && minute <= 30) {
    draw_word(dest,3,0,4,color2); // PAST
  }

  if (minute > 30) {
    draw_word(dest,3,3,2,color2); // TO
    hour = (hour + 1) % 12;
  }

  if (hour == 0) {
    draw_word(dest,5,0,6,color3); // TWELVE
  }

  if (hour == 1) {
    draw_word(dest,8,6,3,color3); // ONE
  }

  if (hour == 2) {
    draw_word(dest,8,4,3,color3); // TWO
  }

  if (hour == 3) {
    draw_word(dest,7,0,5,color3); // THREE
  }

  if (hour == 4) {
    draw_word(dest,4,0,4,color3); // FOUR
  }

  if (hour == 5) {
    draw_word(dest,7,5,4,color3); // FIVE
  }
  
  if (hour == 6) {
    draw_word(dest,5,6,3,color3); // SIX
  }

  if (hour == 7) {
    draw_word(dest,4,4,5,color3); // SEVEN
  }

  if (hour == 8) {
    draw_word(dest,8,0,5,color3); // EIGHT
  }

  if (hour == 9) {
    draw_word(dest,6,0,4,color3); // NINE
  }

  if (hour == 10) {
    draw_word(dest,3,6,3,color3); // TEN
  }

  if (hour == 11) {
    draw_word(dest,6,3,6,color3); // ELEVEN
  }
}

void writeWiFi() {
  for (int i = 0; i < NUM_LEDS; i++) {
    leds[i] = CRGB::Black;
  }

  leds[LETTER_LEDS[5][1][0]] = wifi_color;
  leds[LETTER_LEDS[5][1][1]] = wifi_color;
  
  leds[LETTER_LEDS[6][1][0]] = wifi_color;
  leds[LETTER_LEDS[6][1][1]] = wifi_color;
  
  leds[LETTER_LEDS[7][5][0]] = wifi_color;
  leds[LETTER_LEDS[7][5][1]] = wifi_color;
  
  leds[LETTER_LEDS[7][6][0]] = wifi_color;
  leds[LETTER_LEDS[7][6][1]] = wifi_color;

  show_leds();
}

void blackout() {
  for (int i = 0; i < NUM_LEDS; i++) {
    leds[i] = CRGB::Black;
  }
  show_leds();
}

void setup(){
  Serial.begin(115200);
  DPRINTLN();

  accel.begin(0x18);
  accel.setRange(LIS3DH_RANGE_2_G);

  // It seems there isn't a way to turn off the indicator leds :(
  // But we can at least disable the onboard dotstar.
  tp.DotStar_SetPower( false );

  // We're not going to use bluetooth, just shut it down.
  esp_bt_controller_disable();

  // adafruit dotstar matrix
  FastLED.addLeds<DOTSTAR, SPI_DATA, SPI_CLOCK, BGR>(leds, NUM_LEDS);

  // ensure the arrays are init'ed black
  for (int i = 0; i < NUM_LEDS; i++) {
    leds[i] = CRGB::Black;
    before[i] = CHSV(0, 0, 0);
    after[i] = CHSV(0, 0, 0);
    kevin[i] = CHSV(0, 0, 0);
  }

  // Load the stored values
  read_stored_values();

  setCpuFrequencyMhz(80);
}

int button_seconds() {
  return (millis() - button_start) / 1000;
}

int current_button() {
  return button;
}

bool only_once_per_press() {
  bool ret = button_once;
  button_once = false;
  return ret;
}

bool register_direction(int pressed) {
  if (button != pressed) {
    button = pressed;
    button_since = millis();
    button_start = button_since;
    button_once = true;
    return false;
  }

  int now = millis();
  if (now - button_since > 5000) {
    button_since = now;
    return true;
  }

  return false;
}

void manual_tz_adjust(long diff) {
  if (timeLoaded) {
    // Only modify the timezone if we're already showing the time
    // just in case someone turns on the clock while it's on its side.

    if (manual_tz_offset == UNSET_MANUAL_TZ_OFFSET) {
      manual_tz_offset = timeClient.getTimeOffset();
    }
    manual_tz_offset += diff;
    timeClient.setTimeOffset(manual_tz_offset);
    // force redraw
    timeClient.freezeSys();

    draw_time(after, timeClient.getHours() % 12, timeClient.getMinutes() - timeClient.getMinutes() % 5);
    buffered_minute = 60;
  }
}

// Does appropriate actions for each button!
void update_button() {
  accel.read();

  int32_t x = accel.x;
  int32_t y = accel.y;
  int32_t z = accel.z;

  if (x*x > y*y + z*z) {
    if (x > 0) {
      if (register_direction(ROTATE_LEFT)) {
        DPRINTLN("Pressed left: tz--");
        manual_tz_adjust(-60*60);
      }
    } else {
      if (register_direction(ROTATE_RIGHT)) {
        DPRINTLN("Pressed right: tz++");
        manual_tz_adjust(60*60);
      }
    }
  } else if (y*y > x*x + z*z) {
    if (y > 0) {
      if (register_direction(NORMAL_POSITION)) {
        if (only_once_per_press()) {
          DPRINTLN("Normal position: saving values");
          write_stored_values();
        }
      }
    } else {
      if (register_direction(UPSIDE_DOWN)) {
        // Reset wifi & tz
        if (only_once_per_press() && ESPConnect.isConfigured()) {
          DPRINTLN("Pressed upside down: resetting wifi");
          ESPConnect.erase();
        }
      }
    }
  } else if (z*z > x*x + y*y) {
    if (z > 0) {
      // Reset and reduce brightness
      // If over a minute, reset time zone to auto.
      register_direction(FACE_UP);
      int t = button_seconds();

      if (t > 60 && only_once_per_press()) {
        DPRINTLN("Resetting timezone");
        manual_tz_offset = UNSET_MANUAL_TZ_OFFSET;
        timeLoaded = false;
        buffered_minute = 60;
      }

      uint8_t new_led_value;
      if (t < 5) {
        new_led_value = led_value;
      } else {
        new_led_value = (uint8_t[]){255, 200, 150, 100, 50}[((t-5) / 5) % 5];
      }

      if (new_led_value != led_value) {
        DPRINT("Setting brightness: ");
        DPRINTLN(new_led_value);
        led_value = new_led_value;
      }
    } else {
      if (register_direction(FACE_DOWN)) {
        if (only_once_per_press()) {
          DPRINTLN("Pressed face down: setting display off time");
        }
      }

      if (button_seconds() >= 5) {
        // Don't do anything if the button wasn't pushed for at least 5 seconds
        if (button_seconds() < 300) {
          // In the first 5 minutes of being face down, just reset the display off time.
          display_off_start = display_off_end = 1000000;
        } else {
          // Otherwise, set the display_off_end to now, and start to ~button_start.
          timeClient.freezeSys();
          display_off_end = timeClient.getEpochTime() % 86400L;
          display_off_start = (display_off_end + 86400L - button_seconds()) % 86400L;
        }
      }
    }
  } else {
    if (register_direction(-1)) {
        // Do nothing!
    }
  }
}

void loop() {
  update_button();
  
  if (!ESPConnect.isConfigured()) {
    DPRINTLN("Init network settings");
    // Let's get this over with fast.
    setCpuFrequencyMhz(240);

    wifi_color = CRGB::Red;
    writeWiFi();

    ESPConnect.scanNetworks();

    ESPConnect.startPortal(&server, "Wordclock");

    if (!ESPConnect.connect()) {
      // First WiFi setup failed, clear credentials to try again.
      ESPConnect.erase();
    } else {
      wifi_color = CRGB::Green;
    }

    WiFi.disconnect(true, true);
    WiFi.mode(WIFI_OFF);

    // And let's not melt the cpu.
    setCpuFrequencyMhz(80);

    return;
  }

  if (!timeLoaded) {
    DPRINTLN("Loading time first attempt");
    writeWiFi();

    int result = get_time();

    if (result == NO_WIFI) {
      wifi_color = CRGB::Yellow;
      DPRINTLN("Couldn't connect to wifi");
    } else if (result == NO_API) {
      wifi_color = CRGB::Blue;
      DPRINTLN("Couldn't reach services for time");
    } else if (result == SUCCESS) {
      // Init after time, this will immediately get copied to 'before'.
      timeClient.freezeSys();
      draw_time(after, timeClient.getHours() % 12, timeClient.getMinutes() - timeClient.getMinutes() % 5);
      timeLoaded = true;
    } else {
      // uh oh.
      DPRINTLN("IllegalStateException?");
    }

    // Let the chip cool off a bit.
    if (!timeLoaded) {
      writeWiFi(); // Show the correct color right away.
      delay(4000);
    }

    return;
  }
  
  // Make sure everything that happens this cycle is based on one timestamp.
  timeClient.freezeSys();

  unsigned long current_hour = timeClient.getHours() % 12;
  unsigned long current_minute = timeClient.getMinutes();
  current_minute -= current_minute % 5;

  // Update the display buffers if time has advanced enough.
  unsigned long next_hour = (current_hour + (current_minute == 55 ? 1 : 0)) % 12;
  unsigned long next_minute = (current_minute + 5) % 60;

  if (buffered_minute != current_minute) {
    for (int i = 0; i < NUM_LEDS; i++) {
      before[i] = after[i];
    }

    draw_time(after, next_hour, next_minute);
    buffered_minute = current_minute;

    if (current_minute == 5) {
      // Update at 5 minutes after the hour to best handle DST.
      // There are no animations at xx:05 - xx:06 so it's fine if we wait here for a bit
      get_time();
    }
  }

  // Turn off the display if requested.
  unsigned long day_seconds = timeClient.getEpochTime() % 86400L;
  if (display_off_start <= display_off_end) {
    if (display_off_start <= day_seconds && day_seconds <= display_off_end) {
      blackout();
      return;
    }
  } else {
    if (display_off_start <= day_seconds || day_seconds <= display_off_end) {
      blackout();
      return;
    }
  }

  // Show the time or signature!
  unsigned long interval_millis = (timeClient.getEpochTime() % FIVE_MIN) * 1000 + timeClient.getMillis();

  if (current_hour == 1 && timeClient.getMinutes() == 26) {
    for (unsigned long i = 0; i < 5; i++) {
      // TODO: make sure this looks good
      kevin[LETTER_LEDS[6-i][8-i][0]] = CHSV((25*i + interval_millis/16) % 256, 255, led_value);
      kevin[LETTER_LEDS[6-i][8-i][1]] = CHSV((25*i + interval_millis/16) % 256, 255, led_value);
    }

    unsigned long kevin_millis = interval_millis % MILLIS_PER_MINUTE;
    if (kevin_millis < FADE_MILLIS) {
      draw_buffers(before, kevin, kevin_millis / (1.0 * FADE_MILLIS));
    } else if (kevin_millis < MILLIS_PER_MINUTE - FADE_MILLIS) {
      draw_buffer(kevin);
    } else {
      draw_buffers(kevin, before, (kevin_millis + FADE_MILLIS - MILLIS_PER_MINUTE) / (1.0 * FADE_MILLIS));
    }
  } else if (interval_millis < FADE_START) {
    draw_buffer(before);
  } else if (interval_millis < FADE_END) {
    draw_buffers(before, after, (interval_millis - FADE_START)/(1.0*FADE_MILLIS));
  } else {
    draw_buffer(after);
  }
}

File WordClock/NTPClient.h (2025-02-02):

#pragma once

#include "Arduino.h"

#include <Udp.h>

#define SEVENZYYEARS 2208988800UL
#define NTP_PACKET_SIZE 48
#define NTP_DEFAULT_LOCAL_PORT 1337

class NTPClient {
  private:
    UDP*          _udp;
    bool          _udpSetup       = false;

    const char*   _poolServerName = "pool.ntp.org"; // Default time server
    IPAddress     _poolServerIP;
    unsigned int  _port           = NTP_DEFAULT_LOCAL_PORT;
    long          _timeOffset     = 0;

    unsigned long _updateInterval = 60000;  // In ms

    unsigned long _currentEpoc    = 0;      // In s
    unsigned long _lastUpdate     = 0;      // In ms

    unsigned long _sysMillis      = 0;      // In ms

    byte          _packetBuffer[NTP_PACKET_SIZE];

    void          sendNTPPacket();

  public:
    NTPClient(UDP& udp);
    NTPClient(UDP& udp, long timeOffset);
    NTPClient(UDP& udp, const char* poolServerName);
    NTPClient(UDP& udp, const char* poolServerName, long timeOffset);
    NTPClient(UDP& udp, const char* poolServerName, long timeOffset, unsigned long updateInterval);
    NTPClient(UDP& udp, IPAddress poolServerIP);
    NTPClient(UDP& udp, IPAddress poolServerIP, long timeOffset);
    NTPClient(UDP& udp, IPAddress poolServerIP, long timeOffset, unsigned long updateInterval);

    /**
     * Set time server name
     *
     * @param poolServerName
     */
    void setPoolServerName(const char* poolServerName);

     /**
     * Set random local port
     */
    void setRandomPort(unsigned int minValue = 49152, unsigned int maxValue = 65535);

    /**
     * Starts the underlying UDP client with the default local port
     */
    void begin();

    /**
     * Starts the underlying UDP client with the specified local port
     */
    void begin(unsigned int port);

    /**
     * This should be called in the main loop of your application. By default an update from the NTP Server is only
     * made every 60 seconds. This can be configured in the NTPClient constructor.
     *
     * @return true on success, false on failure
     */
    bool update();

    /**
     * This will force the update from the NTP Server.
     *
     * @return true on success, false on failure
     */
    bool forceUpdate();

    /**
     * This allows to check if the NTPClient successfully received a NTP packet and set the time.
     *
     * @return true if time has been set, else false
     */
    bool isTimeSet() const;

    int getDay() const;
    int getHours() const;
    int getMinutes() const;
    int getSeconds() const;
    int getMillis() const;

    /**
     * Changes the time offset. Useful for changing timezones dynamically
     */
    void setTimeOffset(long timeOffset);

    long getTimeOffset();

    /**
     * Set the update interval to another frequency. E.g. useful when the
     * timeOffset should not be set in the constructor
     */
    void setUpdateInterval(unsigned long updateInterval);

    /**
     * @return time formatted like `hh:mm:ss`
     */
    String getFormattedTime() const;

    /**
     * @return time in seconds since Jan. 1, 1970
     */
    unsigned long getEpochTime() const;

    unsigned long getMillisSinceUpdate() const;

    void freezeSys();

    /**
     * Stops the underlying UDP client
     */
    void end();
};
